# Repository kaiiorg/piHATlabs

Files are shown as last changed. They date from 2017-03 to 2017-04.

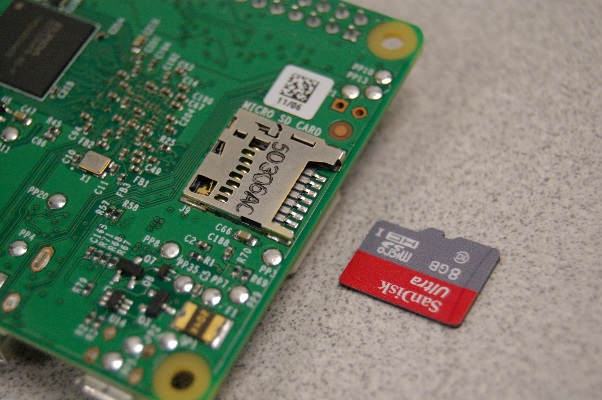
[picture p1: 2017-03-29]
images/1/7.6a.jpg

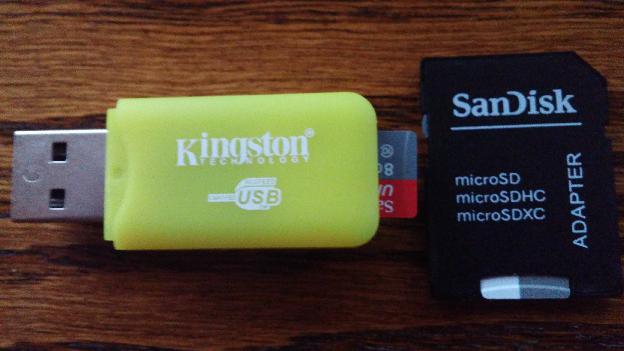
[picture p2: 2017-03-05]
images/1/5.1.jpg

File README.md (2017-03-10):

#PI HAT Labs
These are labs for a HAT originally designed as part of an independent study for Southeast Missouri State Universities' Department of Polytechnic Studies. It is designed for basic learning of Raspberry PI GPIO programming, using LEDs, switches, and a shift register with a seven segment display. The board also has additional headers on the various communications buses of the PI, to make it slightly easier to expand the hat while still using the components it supplies.

**_Snark Warning:_** If you think your students are special little snow flakes that need to be protected or take offense at every little thing, I suggest you don't bother reading the rest of this or consider deploying these labs to your students. I wrote these labs in a manner that I would have wanted: not boring or bland, with lots of useful information, with an occasional poke or prod to keep things interesting. This is written for _actual_ university level students. Freshman and sophomore level students, sure, but university students. Emailing me about the level of snark in these labs will only get you ignored.

##Instructors: Supply Your Students With These Materials:
1. A Raspberry Pi 2 or newer
2. A USB AC power adapter
3. An HDMI cable (or a cable that is HDMI -> whatever your lab's monitors support)
4. USB Mouse
5. USB Keyboard
6. Ethernet Cable
7. Network access to access these labs via web browser. Internet access required for some elements to load correctly.
8. Access to a Windows (7 to 10 should work) computer for the first lab, the other labs can be completed entirely on the PI.

##Lab 1: Install Rasbian on a Raspberry PI
Students learn to install the Rasbian OS onto a Raspberry PI. They will need access to a Windows computer for this part.
**_Instructors:_ Read the bottom of lab 1! You will need to manually download the Raspbian image and follow the directions there.**

##Lab 2: Test the HAT
Students learn about the physical layout of the HAT and run their first python program. This program tests all the components for functionality.

##Lab 3: GPIO Input and Output
Students learn basic electrical schematic elements and the electrical schematic of the HAT. They learn to turn the LEDs on or off and how that code works. They learn how to read input from the buttons and how that code works.

##Lab 4: Using a shift register
Students learn a little bit of binary, binary to decimal conversion, binary to hexidecimal conversion, how a shift register works, how to *use* a shift register

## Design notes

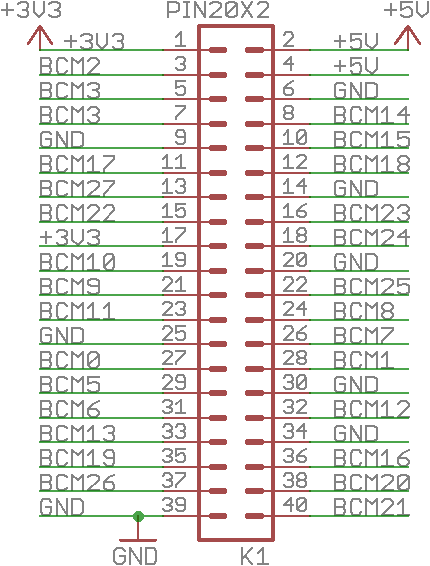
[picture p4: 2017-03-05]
images/3/sch.5.png

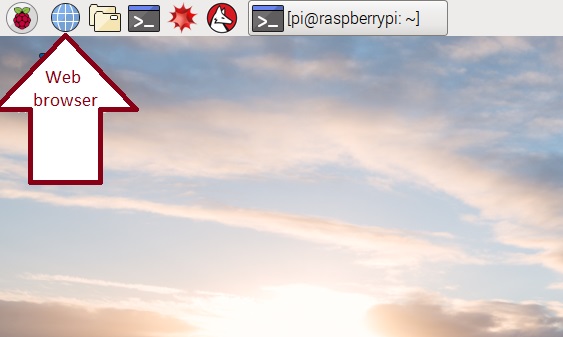
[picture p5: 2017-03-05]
images/1/8.1.jpg

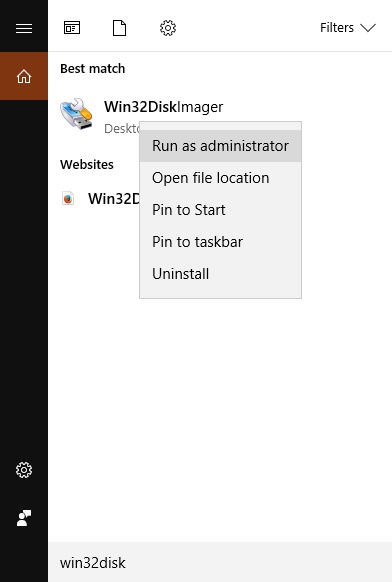
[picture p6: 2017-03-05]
images/1/6.1.jpg

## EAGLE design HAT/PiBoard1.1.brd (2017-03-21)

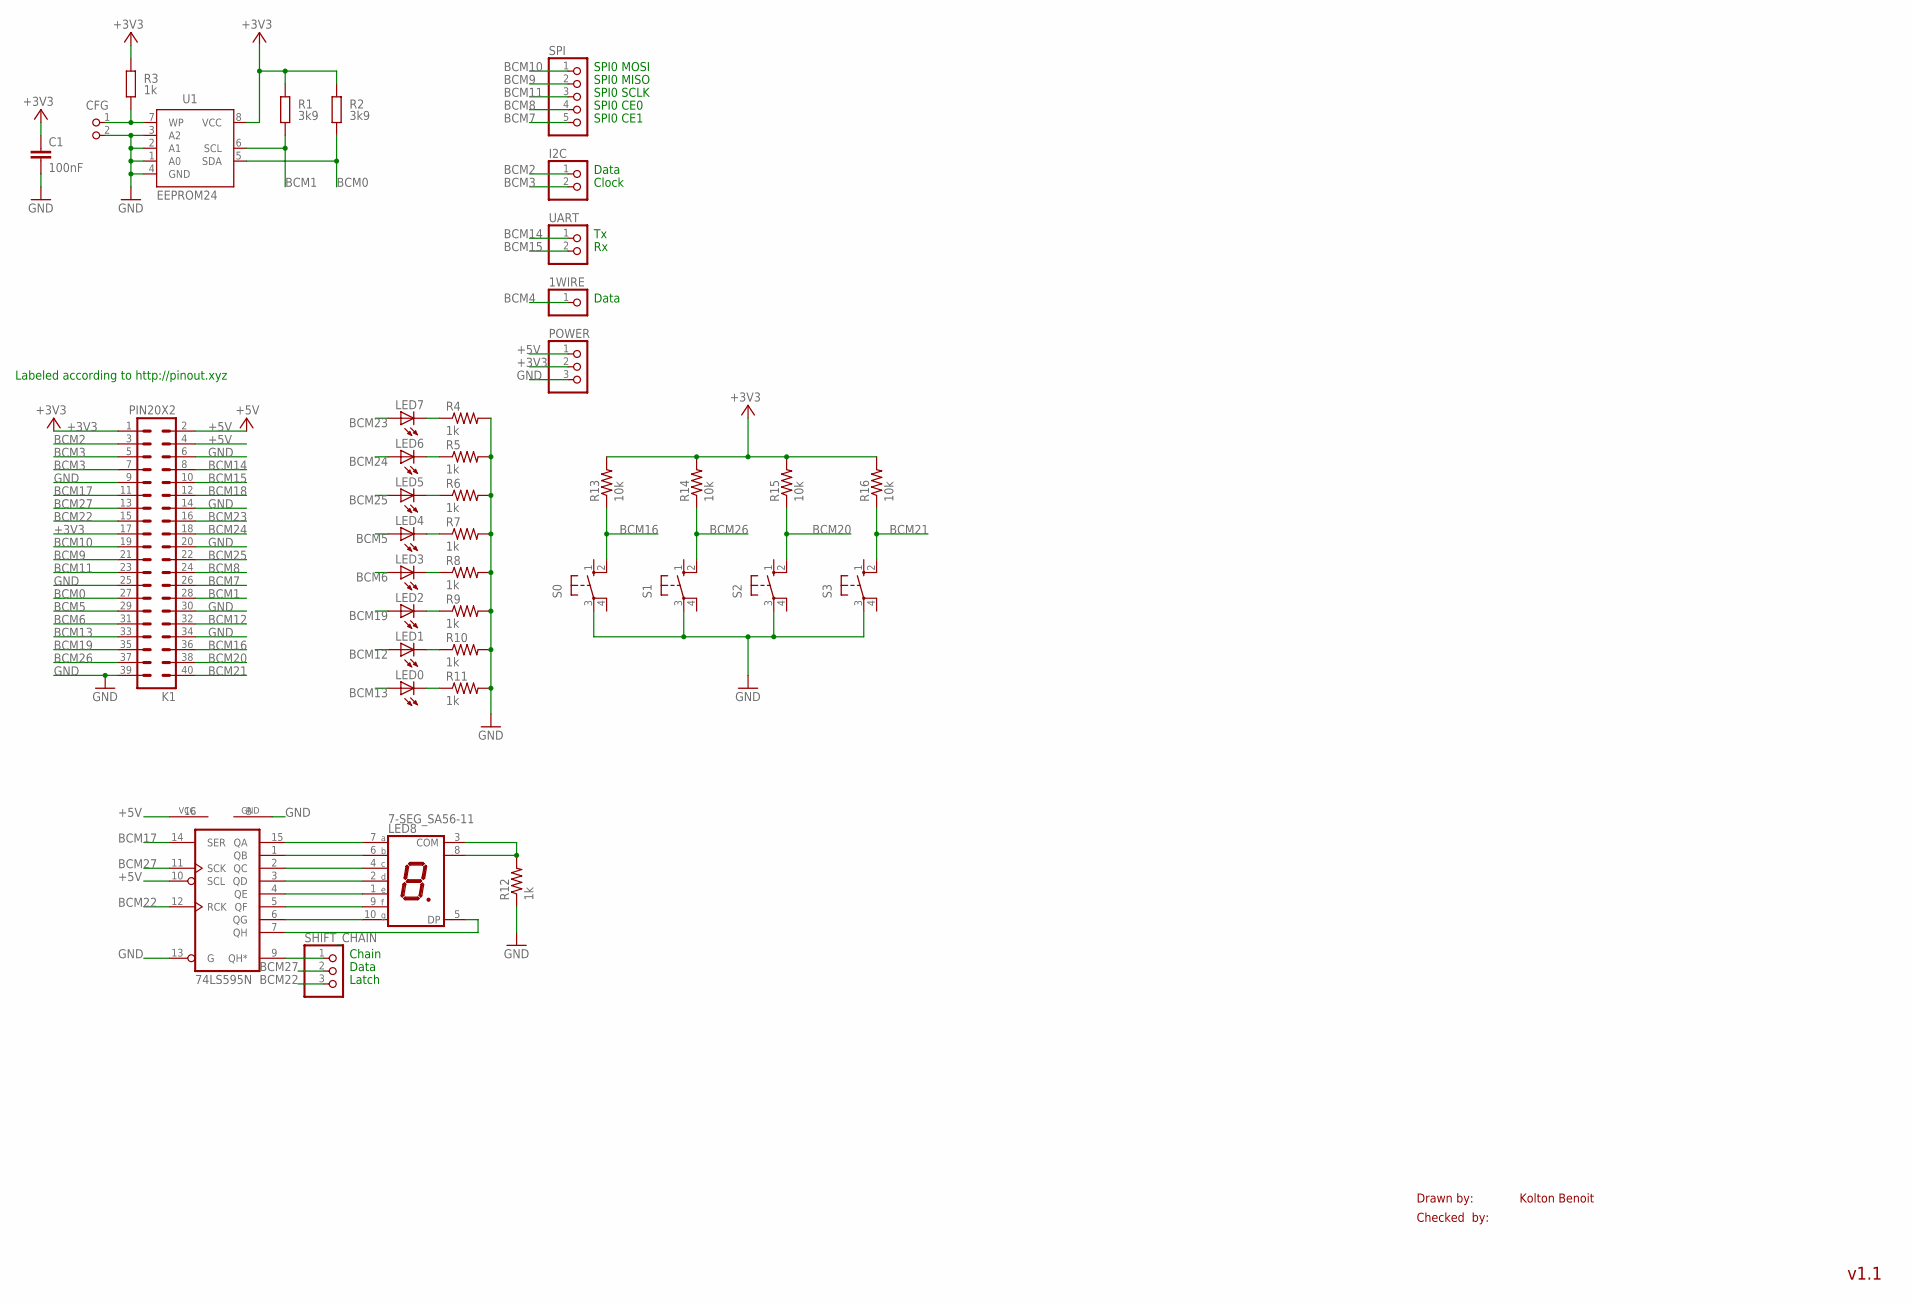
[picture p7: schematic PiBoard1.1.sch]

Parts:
1WIRE: PINHD-1X1; 1X01
C1: 100nF; C0805K
CFG: PIN2_100; PIN_W_2
I2C: PINHD-1X2; 1X02
K1: PIN20X2; PIN_20X2
LED0, LED1, LED2, LED3, LED4, LED5, LED6, LED7: LED3MM
LED8: 7-SEG_SA56-11; SA56-11
POWER: PINHD-1X3; 1X03
R1, R2: 3k9; M0805@1; TOLERANCE 5%
R3: 1k; M0805@1; TOLERANCE 5%
R4, R5, R6, R7, R8, R9, R10, R11, R12: 1k; 0204/7
R13, R14, R15, R16: 10k; 0204/7
S0, S1, S2, S3: 10-XX; B3F-10XX
SHIFT: 74LS595N; DIL16
SHIFT_CHAIN: PINHD-1X3; 1X03
SPI: PINHD-1X5; 1X05
U1: EEPROM24; SOIC8
UART: PINHD-1X2; 1X02

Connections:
+3V3: C1.1, K1.1, K1.17, POWER.2, R1.2, R2.2, R3.2, R13.2, R14.2, R15.2, R16.2, U1.8 (VCC)
+5V: K1.2, K1.4, POWER.1, SHIFT.10 (SCL), SHIFT.16 (VCC)
BCM0: K1.27, R2.1, U1.5 (SDA)
BCM1: K1.28, R1.1, U1.6 (SCL)
BCM2: I2C.1, K1.3
BCM3: I2C.2, K1.5
BCM4: 1WIRE.1, K1.7
BCM5: K1.29, LED4.A
BCM6: K1.31, LED3.A
BCM7: K1.26, SPI.5
BCM8: K1.24, SPI.4
BCM9: K1.21, SPI.2
BCM10: K1.19, SPI.1
BCM11: K1.23, SPI.3
BCM12: K1.32, LED1.A
BCM13: K1.33, LED0.A
BCM14: K1.8, UART.1
BCM15: K1.10, UART.2
BCM16: K1.36, R13.1, S0.2 (S1)
BCM17: K1.11, SHIFT.14 (SER)
BCM18: K1.12
BCM19: K1.35, LED2.A
BCM20: K1.38, R15.1, S2.2 (S1)
BCM21: K1.40, R16.1, S3.2 (S1)
BCM22: K1.15, SHIFT.12 (RCK), SHIFT_CHAIN.3
BCM23: K1.16, LED7.A
BCM24: K1.18, LED6.A
BCM25: K1.22, LED5.A
BCM26: K1.37, R14.1, S1.2 (S1)
BCM27: K1.13, SHIFT.11 (SCK), SHIFT_CHAIN.2
GND: C1.2, CFG.2, K1.6, K1.9, K1.14, K1.20, K1.25, K1.30, K1.34, K1.39, POWER.3, R4.2, R5.2, R6.2, R7.2, R8.2, R9.2, R10.2, R11.2, R12.1, S0.3, S1.3, S2.3, S3.3, SHIFT.8 (GND), SHIFT.13 (G), U1.1 (A0), U1.2 (A1), U1.3 (A2), U1.4 (GND)
unnamed: CFG.1, R3.1, U1.7 (WP)
unnamed: LED8.7 (A), SHIFT.15 (QA)
unnamed: LED8.6 (B), SHIFT.1 (QB)
unnamed: LED8.4 (C), SHIFT.2 (QC)
unnamed: LED8.2 (D), SHIFT.3 (QD)
unnamed: LED8.1 (E), SHIFT.4 (QE)
unnamed: LED8.9 (F), SHIFT.5 (QF)
unnamed: LED8.10 (G), SHIFT.6 (QG)
unnamed: LED8.5 (DP), SHIFT.7 (QH)
unnamed: LED0.K (C), R11.1
unnamed: LED1.K (C), R10.1
unnamed: LED2.K (C), R9.1
unnamed: LED3.K (C), R8.1
unnamed: LED4.K (C), R7.1
unnamed: LED5.K (C), R6.1
unnamed: LED6.K (C), R5.1
unnamed: LED7.K (C), R4.1
unnamed: SHIFT.9 (QH*), SHIFT_CHAIN.1
unnamed: LED8.3 (COM), LED8.8 (COM), R12.2

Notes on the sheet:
Drawn by:
Checked by:
Kolton Benoit
v1.1
SPI0 MOSI
SPI0 MISO
SPI0 SCLK
SPI0 CE0
SPI0 CE1
Data
Clock
Chain
Latch
Labeled according to http://pinout.xyz

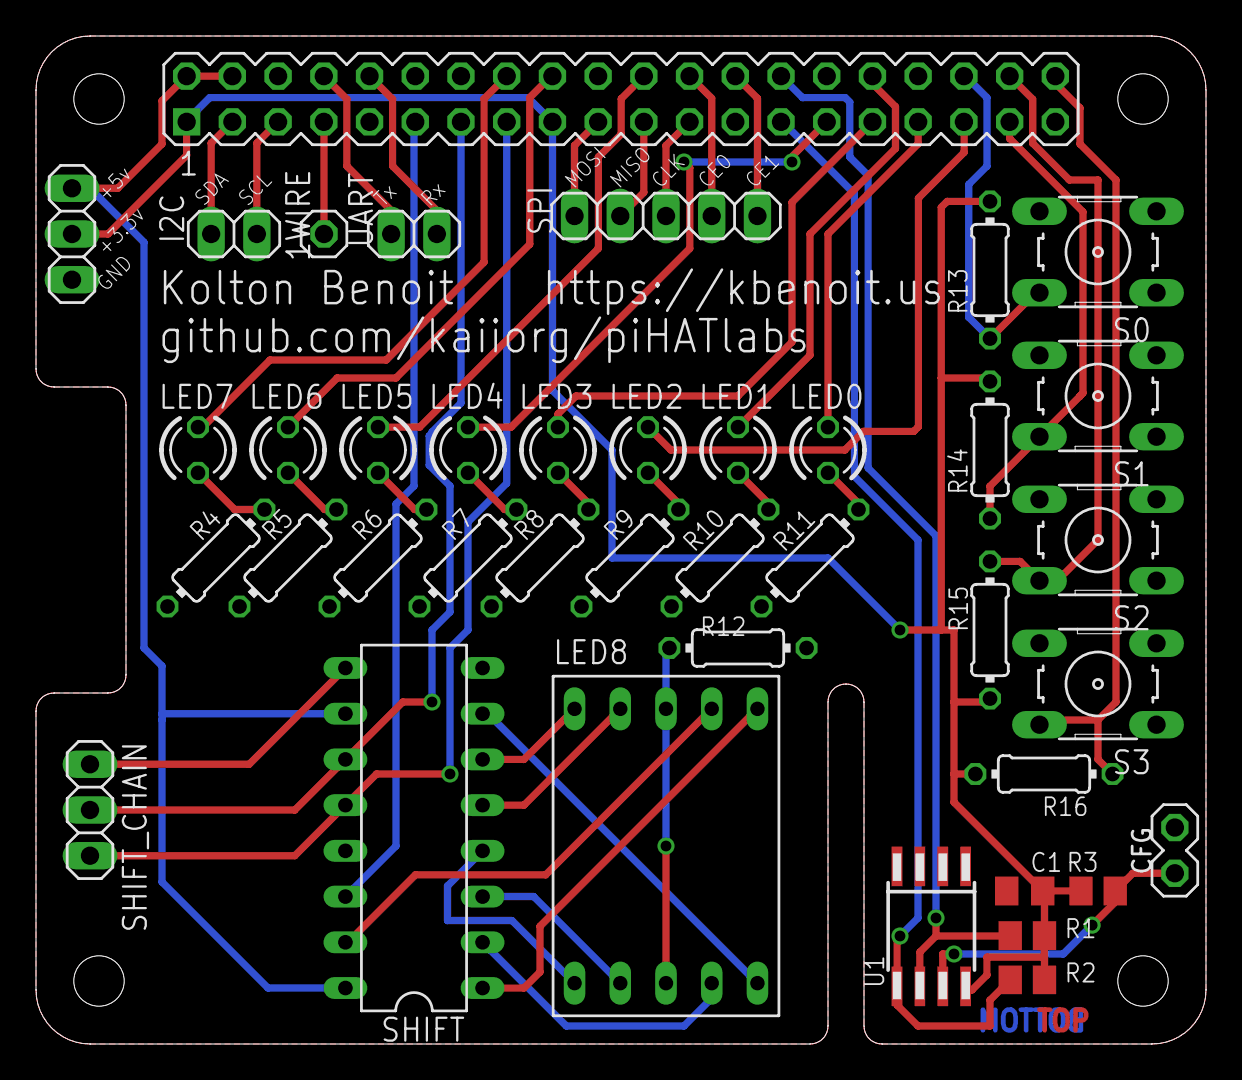
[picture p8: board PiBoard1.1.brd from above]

Board: 2 copper layers, 65.0 x 56.0 mm, 40 parts (0 on the bottom side), 49 nets.

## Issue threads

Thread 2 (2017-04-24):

/3/buttons.py is still broken

kaiiorg, 2017-04-24:

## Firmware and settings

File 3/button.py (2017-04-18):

#!/usr/bin/python
#Lab 3: 

#import time.sleep
from time import sleep

#Import the RPi.GPIO module
import RPi.GPIO as GPIO
#Select the BCM mode
GPIO.setmode(GPIO.BCM)

#List of BCM pin numbers of the buttons
buttons = [16, 26, 20, 21]
#Setup the button pins
for button in buttons:
	GPIO.setup(button, GPIO.IN)

#Counter variable
i = 0

#Loop indefinitely
while True:
	try:
		#Check to see if each button has been pressed, output the number of button that was pressed.
		while i < 4
			if GPIO.input(buttons[i]) != GPIO.LOW:
				print(str.format("You pressed button {0}!", i))
				#Debounce
				time.sleep(0.01)
			i += 1
		i = 0
		time.sleep(0.01)
	except KeyboardInterrupt:
		break

GPIO.cleanup()

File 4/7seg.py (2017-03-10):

#!/usr/bin/python
#Lab 4: Using a shift register
#Import the time and sys modules
import time, sys
#Import the RPi.GPIO module
import RPi.GPIO as GPIO
#Select the BCM mode
GPIO.setmode(GPIO.BCM)

#Pins for shift register
dataPin = 17
clockPin = 27
latchPin = 22

#Segment data to show the digit 0 to 9 on the 7 segment display
segments = [0xFC, 0x60, 0xDA, 0xF2, 0x66, 0xB6, 0x3E, 0xE0, 0xFE, 0xF6]

#function for driving the shift register
#assumes the dataPin and clockPin have already been setup
#Only does the 8 LSB of output
def	shiftOut(dataPin, clockPin, output, msbFirst):
	GPIO.output(dataPin, GPIO.LOW)
	GPIO.output(clockPin, GPIO.LOW)
	
	
	mask = 1
	if(msbFirst):
		mask <<= 7
		c = 7;
		while c >= 0:
			GPIO.output(dataPin, ((mask & output) >> c) == 1)
			toggle(clockPin)
			mask >>= 1
			c-= 1
	else:
		c = 0
		while c < 8:
			GPIO.output(dataPin, ((mask & output) >> c) == 1)
			toggle(clockPin)
			mask <<= 1
			c+= 1
	return

#toggle the given pin
#assumes it is already setup
def toggle(pin):
	GPIO.output(pin, GPIO.LOW)
	time.sleep(0.0001)
	GPIO.output(pin, GPIO.HIGH)
	time.sleep(0.0001)
	GPIO.output(pin, GPIO.LOW)



#Setup the data, clock, and latch pins
GPIO.setup(dataPin, GPIO.OUT)
GPIO.output(dataPin, GPIO.LOW)
GPIO.setup(clockPin, GPIO.OUT)
GPIO.output(clockPin, GPIO.LOW)
GPIO.setup(latchPin, GPIO.OUT)
GPIO.output(latchPin, GPIO.LOW)


while True:
	try:
		for segment in segments:
			shiftOut(dataPin, clockPin, segment, False)
			toggle(latchPin)
			time.sleep(0.25)
			shiftOut(dataPin, clockPin, segment | 1, False)
			toggle(latchPin)
			time.sleep(0.25)
	except KeyboardInterrupt:
			shiftOut(dataPin, clockPin, 0, False)
			toggle(latchPin)
			break
	
GPIO.cleanup()

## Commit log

2017-03-05 Fixed bug in leds.py. Made progress on lab 4
    [leds.py]
2017-03-21 Added the HAT's source files
    [PiBoard1.1.brd, PiBoard1.1.sch]
2017-03-29 Fixed label in board schematic
    [PiBoard1.1.sch]
2017-04-18 Changed the test script's wording. Hopefully fixed the bug in button.py. Still need to add instructions for changing keyboard country
    [button.py, test.py]
